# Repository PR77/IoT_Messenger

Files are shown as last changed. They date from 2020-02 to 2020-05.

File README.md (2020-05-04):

# IoT_Messenger
IoT Messenger (Pager) For Simple 1 Way Communication

# Warning
This design has not been compliance tested and will not be. It is published purely for inspiration to others. I take no responsibility for damages caused directly or indirectly. I accept no responsibility for any damage to any equipment that results from the use of this design and its components. IT IS ENTIRELY AT YOUR OWN RISK!

# Overview
As a child growing up in the 80's I have fond memories of old skool pagers and analog mobile phones the size of bricks. I remember buying a bunch of old analog Motorola (R) Brick Phones just before the analog network was shut down and turning them into scanners. This project is in no way connected to that, but the fond memory of pagers is something I wanted to bing back with this project. In addition to this, my other motivation for the project was it's "semi" practical use as a real pager within a known WiFi network.

## Basic Concept
My IoT Messenger is essentially some common components connected to an ESP8266, ESP12-F to be specific. However, it is the form factor and user interface which draws parallels to a pager. It is my first revision of the project and has a lot fo fine tuning - should I or the community want to pursue it further. I would like to continue improving this as I see it would be fun for those who use it.

Interfacing with the device is via the Web using the simple HTTP Server class. The IoT Messenger sends out a webpage where the message and other functions can be accessed. As my HTML and JS skills are not up there, I have resorted to using CURL during development and debugging - HELP NEEDED! :)

Here is a nice 3d model of the PCB;

### Appearance
Nice 3D model:
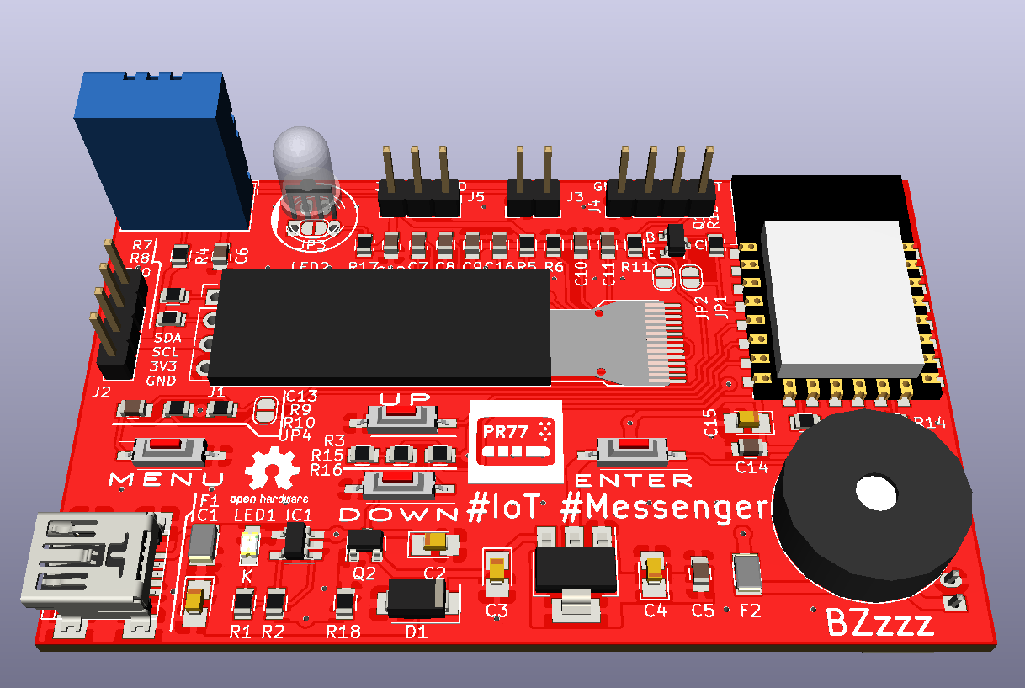
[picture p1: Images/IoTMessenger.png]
3DModel


### Basic Interfaces
My IoT Messenger needs to be portable therefore battery power and a basic set of controls are essential. I use a 600 mA LiPo cell which is charged via USB. USB provides power only. No intelligent power management has been implemented yet, so when running only via battery it last 4 - 5 hours.

There are 4 buttons for user input which can also be used for additional functions (see how Tetris and Dino game use them).

### Power Supply
I use the MCP73831 LiPo battery charger with a P-Channel load balancing FET. This is to ensure the LiPo charger only charges the battery when connected to a USB power source. The necessary 3.3 volts is obtained via a basic LM1117-3.3.

### Sensors And Indicators
I wanted to have the PCB somewhat universal - I guess like an evaluation or child friendly development board - so I added a nice RGB LED (PL9823) and an environmental sensor (DHT11). In addition to these, as the device is inspired by pagers, it has a OLED display (128x32) and Piezo Beeper.

As mentioned, flexibility was important so with the OLED, it is essentially dual-footprinted where a module with necessary passives could just be solder on, or the raw OLED panel and necessary passives be soldered on the IoT Messenger board. For my prototype I used the latter so get some experience with this. Lastly, I added a SAO port, well for - Add Ons.

Nice fully soldered IoT Messenger:
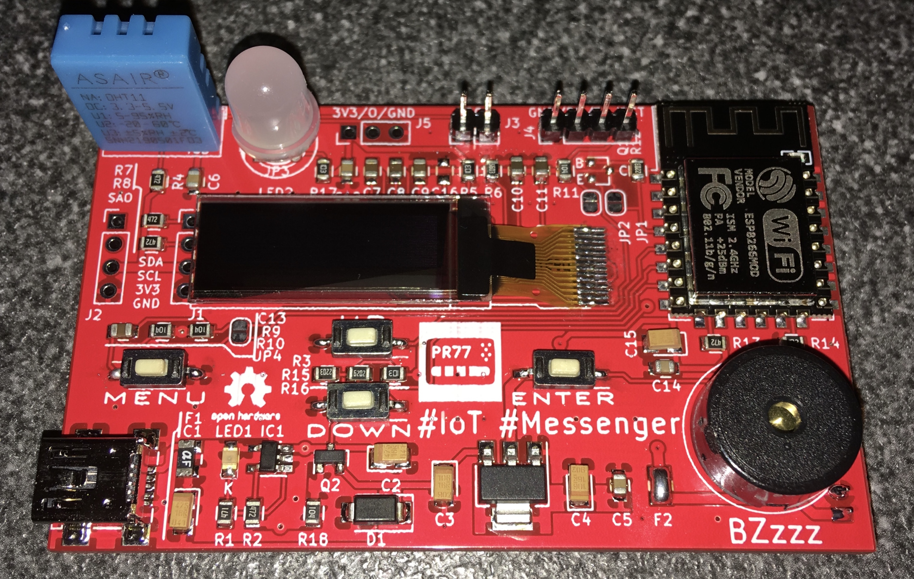
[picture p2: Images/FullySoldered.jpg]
FullySoldered


### Server
All of the interfacing with the hardware features is via HTTP Server GET and POST requests. The following services have been implemented currently;

|Request |Type|Parameters|Comments |
|---|----|---|---|
|/list |GET |none |Lists files currently saved to SPIFFS |
|/upload |POST|filename  |Uploads a file to SPIFFS |
|/format |POST|none |Formats SPIFFS |
|/info |GET |none |Get SPIFFS and CPU MHz info |
|/sensor |GET |none |Read environmental sensor data (DHT11)|
|/message|POST|text |Write a message to the buffer |
|/led |POST|colour |Set RGB LED colour |
|/beeper |POST|count |Beep piezo beeper |

### Fun Stuff
Of course. Check out my IoT Messenger playing the Tetris game theme music or Dino Jump. Videos are in the Images folder.

## Open Sources Used
PlatformIO is the main development environment. In addition to the Arduino framework for ESP8266, I used the following (either important as libraries into PIO or seperate);

1. OLED library (https://github.com/ThingPulse/esp8266-oled-ssd1306)
2. ClickButton library (https://github.com/pkourany/clickButton)
3. RGB LED library (https://github.com/Makuna/NeoPixelBus)
4. Tetris theme song (https://dragaosemchama.com/en/2019/02/songs-for-arduino/)
5. Environmental sensor library (https://github.com/beegee-tokyo/DHTesp)

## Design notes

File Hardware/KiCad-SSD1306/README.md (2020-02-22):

# KiCad-SSD1306_OLED-0.91-128x32

These are the KiCad files I create for the I2C SSD1306 0.91" 128x32 OLED display i used in my [Electrocard](http://michaelteeuw.nl/tagged/electrocard). I included a step file which can be used in a 3D rendering.

The absolute cumbersome and awful way of KiCad to manage libraries probably results in a wrongly setup directory or file structure for this KiCad part. Feel free to send a PR if it turns out it needs a different structure.

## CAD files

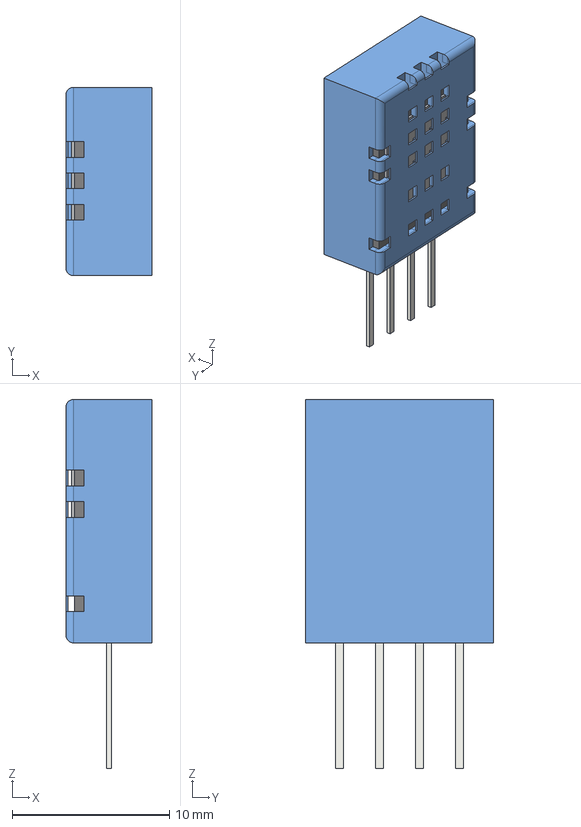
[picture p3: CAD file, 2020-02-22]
Hardware/KiCad-Sensors/Aosong_DHT11_5.5x12.0_P2.54mm.step
5.50 x 12.0 x 23.5 mm

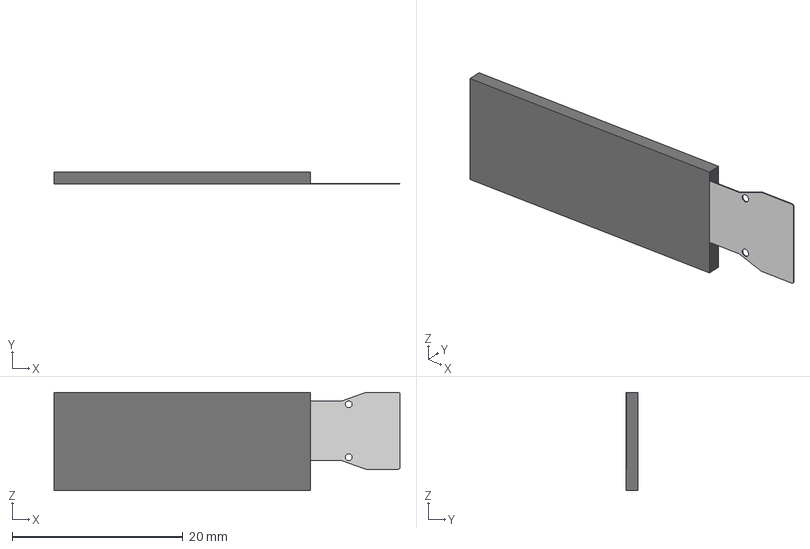
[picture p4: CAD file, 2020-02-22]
Hardware/KiCad-SSD1306/SSD1306_OLED-0.91-128x32.step
40.5 x 1.45 x 11.5 mm

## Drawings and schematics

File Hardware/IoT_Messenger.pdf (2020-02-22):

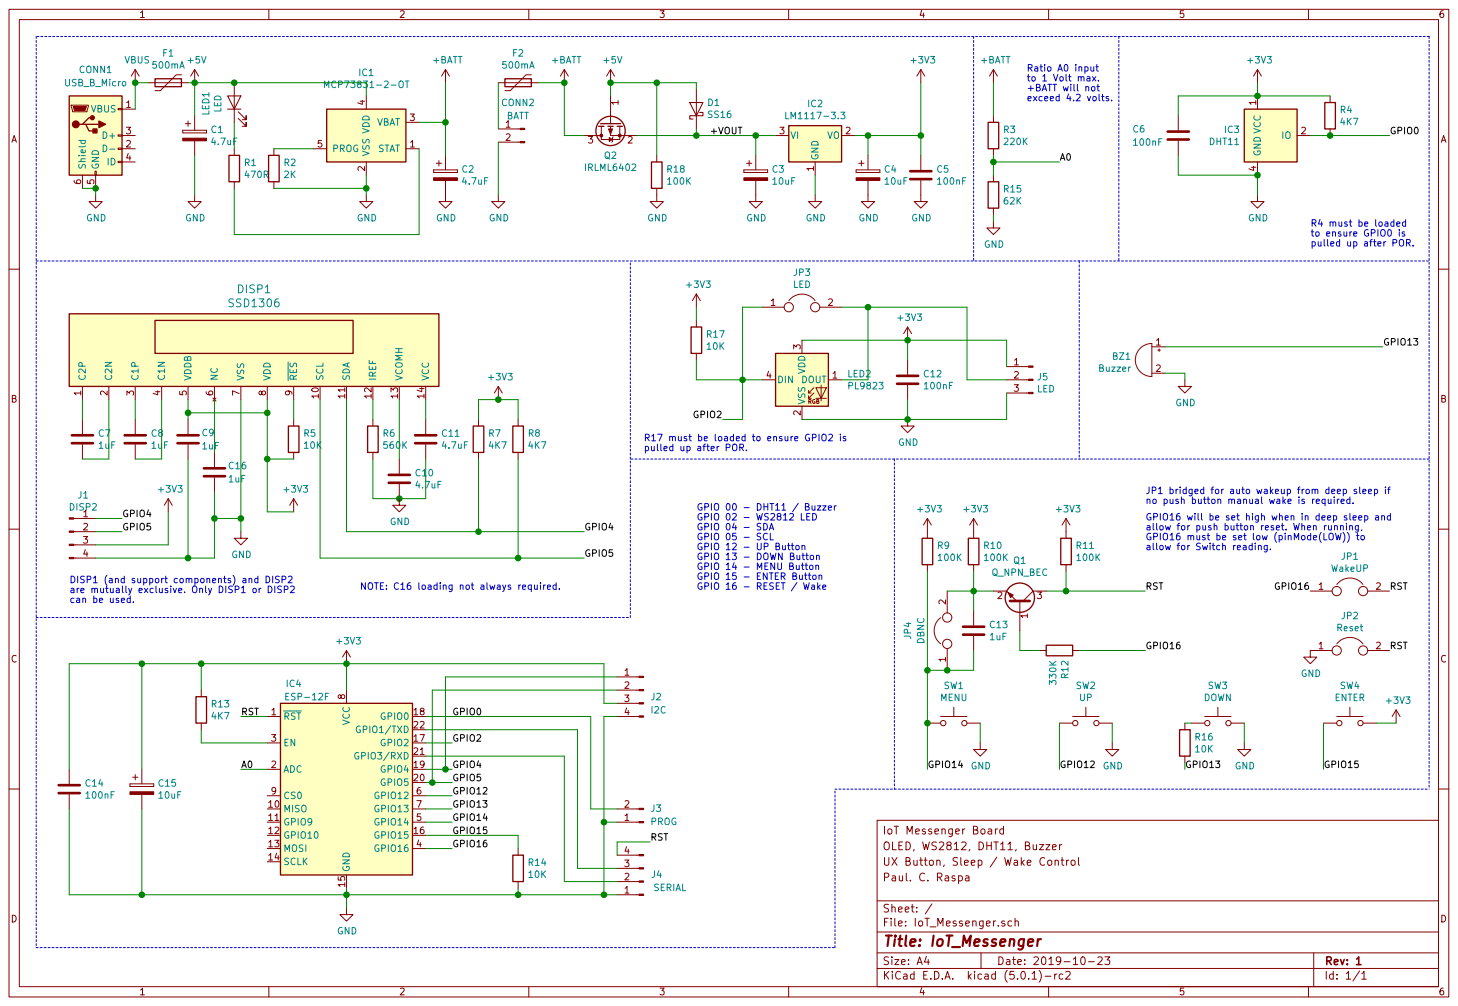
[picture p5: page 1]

Ratio A0 input
to 1 Volt max. +BATT will not exceed 4.2 volts.

4 PROG 5
+3V3 R17 must be loaded to ensure GPIO2 is pulled up after POR. RST

to ensure GPIO0 is pulled up after POR. R17

+3V3 GPIO4 GPIO5 +3V3 DISP1 (and support components) and DISP2

1 SCL 10 SDA 11 IREF 12 VCOMH 13 VCC 14 C2N

JP1 bridged for auto wakeup from deep sleep if

allow for push button reset. When running,
GPIO16 must be set low (pinMode(LOW)) to

allow for Switch reading. GPIO12 GPIO13 GPIO14 GPIO15 GPIO0

are mutually exclusive. Only DISP1 or DISP2

OLED, WS2812, DHT11, Buzzer
UX Button, Sleep / Wake Control
File: IoT_Messenger.sch Sheet: / Paul. C. Raspa

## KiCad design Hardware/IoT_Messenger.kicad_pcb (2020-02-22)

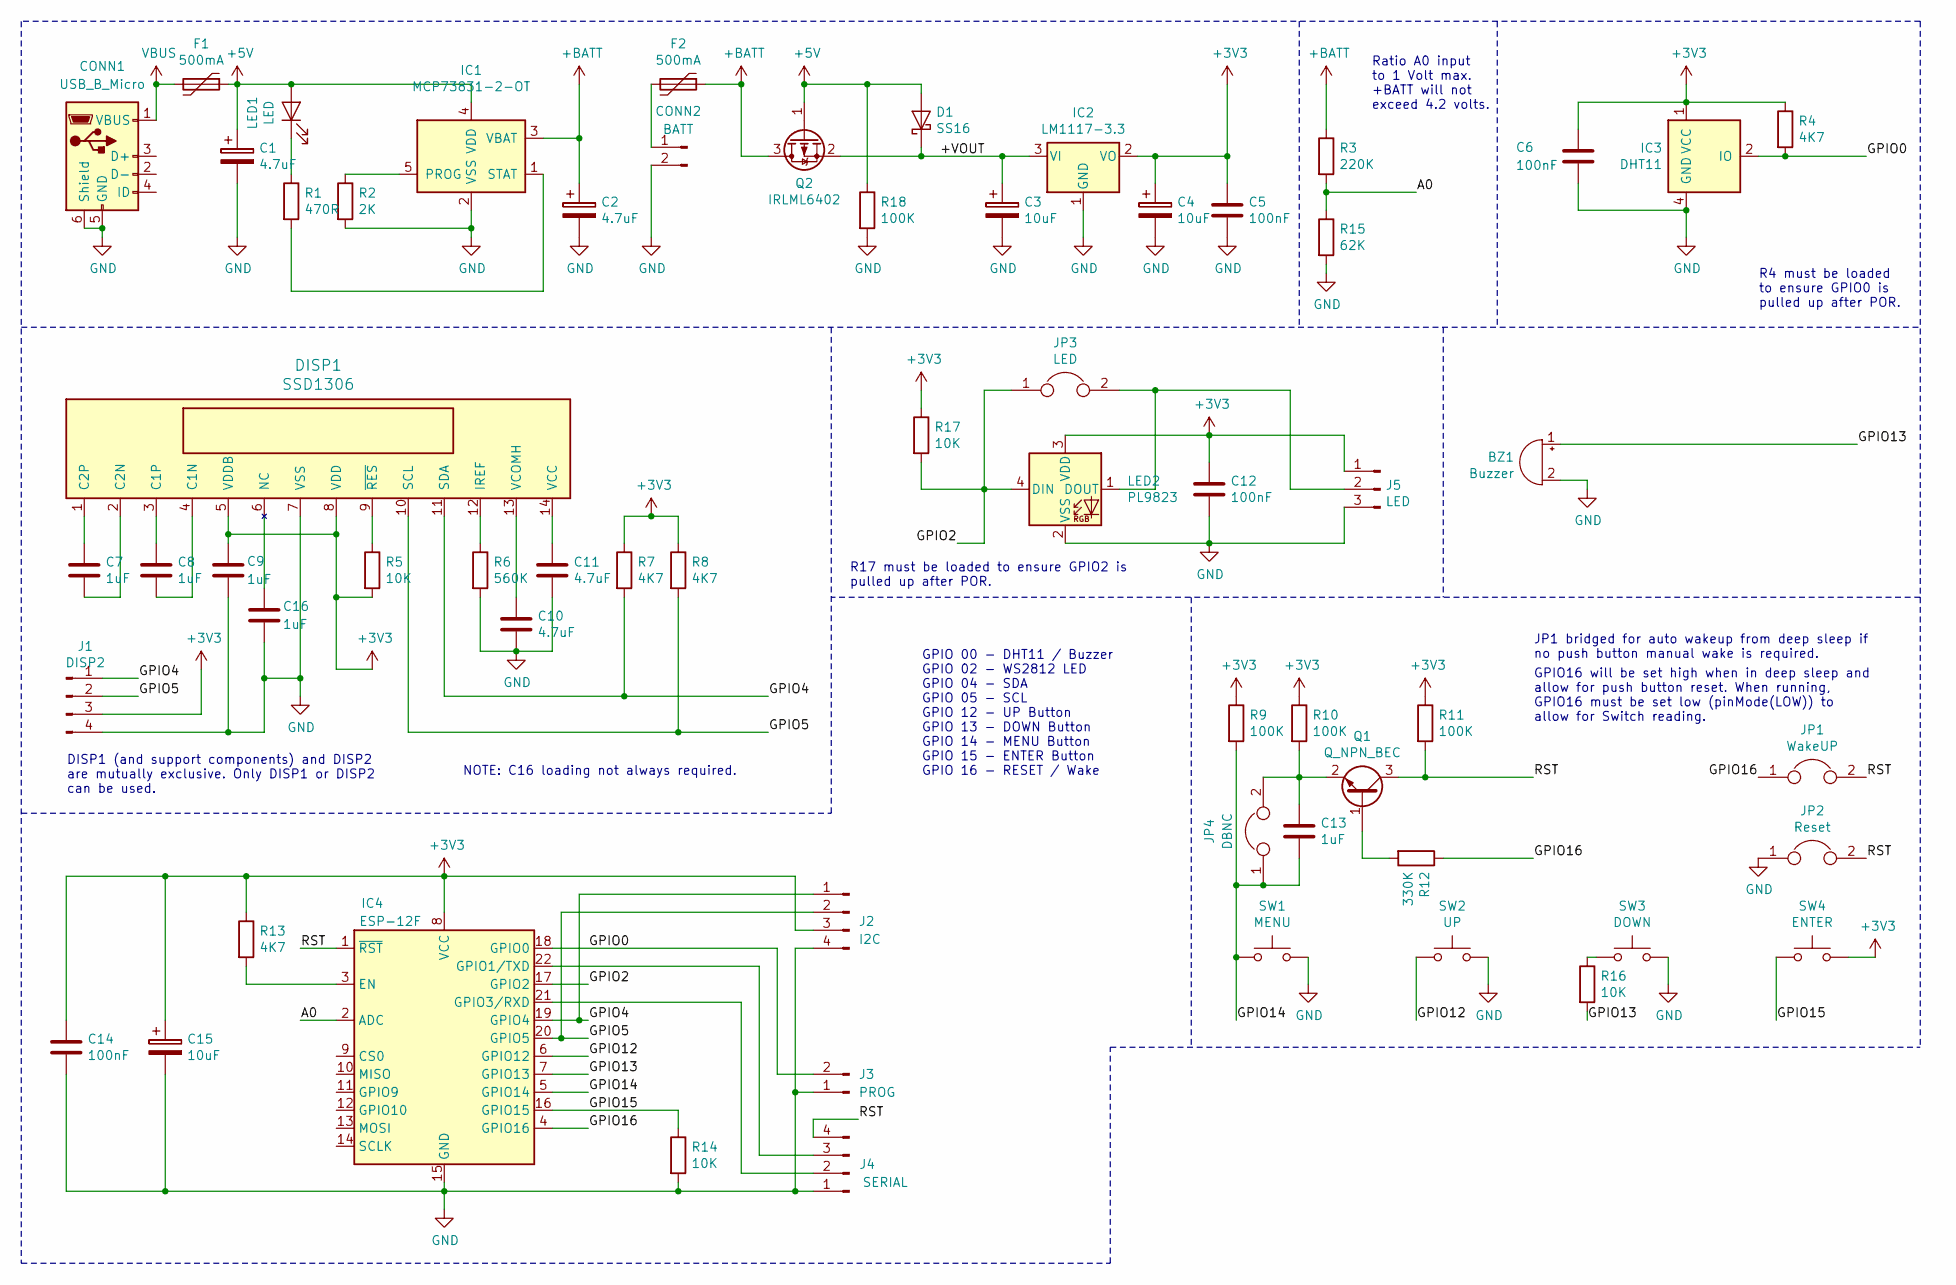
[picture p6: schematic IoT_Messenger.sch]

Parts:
BZ1: Buzzer; Buzzer_15x7.5RM7.6
C1, C2: 4.7uF; CP_Tantalum_Case-R_EIA-2012-12_Reflow
C3, C4, C15: 10uF; CP_Tantalum_Case-R_EIA-2012-12_Reflow
C5, C6, C12, C14: 100nF; C_0805
C7, C8, C9, C13, C16: 1uF; C_0805
C10, C11: 4.7uF; C_0805
CONN1: USB_B_Micro; USB_Mini-B
CONN2: BATT; JST_PH_S2B-PH-K_02x2.00mm_Angled
D1: SS16; D_SMA
DISP1: SSD1306; SSD1306_OLED-0.91-128x32
F1, F2: 500mA; Fuse_SMD1206_Reflow
IC1: MCP73831-2-OT; SOT-23-5_HandSoldering
IC2: LM1117-3.3; SOT-223-3_TabPin2
IC3: DHT11; Aosong_DHT11_5.5x12.0_P2.54mm
IC4: ESP-12F; ESP-12E
J1: DISP2; Pin_Header_Straight_1x04_Pitch2.54mm
J2: I2C; Pin_Header_Straight_1x04_Pitch2.54mm
J3: PROG; Pin_Header_Straight_1x02_Pitch2.54mm
J4: SERIAL; Pin_Header_Straight_1x04_Pitch2.54mm
J5: LED; Pin_Header_Straight_1x03_Pitch2.54mm
JP1: WakeUP; SolderJumper-2_P1.3mm_Open_RoundedPad1.0x1.5mm
JP2: Reset; SolderJumper-2_P1.3mm_Open_RoundedPad1.0x1.5mm
JP3: LED; SolderJumper-2_P1.3mm_Open_RoundedPad1.0x1.5mm
JP4: DBNC; SolderJumper-2_P1.3mm_Open_RoundedPad1.0x1.5mm
LED1: LED; LED_0805
LED2: PL9823; LED_D5.0mm-4
Q1: Q_NPN_BEC; SOT-23
Q2: IRLML6402; SOT-23
R1: 470R; R_0805
R2: 2K; R_0805
R3: 220K; R_0805
R4, R7, R8, R13: 4K7; R_0805
R5, R14, R16, R17: 10K; R_0805
R6: 560K; R_0805
R9, R10, R11, R18: 100K; R_0805
R12: 330K; R_0805
R15: 62K; R_0805
SW1: MENU; SW_DIP_x1_W7.62mm_Slide_Copal_CHS-B
SW2: UP; SW_DIP_x1_W7.62mm_Slide_Copal_CHS-B
SW3: DOWN; SW_DIP_x1_W7.62mm_Slide_Copal_CHS-B
SW4: ENTER; SW_DIP_x1_W7.62mm_Slide_Copal_CHS-B

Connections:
+3V3: C4.1, C5.1, C6.1, C9.1, C12.1, C14.1, C15.1, DISP1.5 (VDDB), DISP1.8 (VDD), IC2.2 (VO), IC3.1 (VCC), IC4.8 (VCC), J1.3, J2.3, J5.1, LED2.3 (VDD), R4.1, R5.2, R7.1, R8.1, R9.1, R10.1, R11.1, R13.1, R17.1, SW4.2
+5V: C1.1, D1.2 (A), F1.1, IC1.4 (VDD), LED1.2 (A), Q2.1 (G), R18.1
+BATT: C2.1, F2.1, IC1.3 (VBAT), Q2.3 (D), R3.1
/+VOUT: C3.1, D1.1 (K), IC2.3 (VI), Q2.2 (S)
/A0: IC4.2 (ADC), R3.2, R15.1
/GPIO0: IC3.2 (IO), IC4.18 (GPIO0), J3.2, R4.2
/GPIO2: IC4.17 (GPIO2), JP3.1, LED2.4 (DIN), R17.2
/GPIO4: DISP1.11 (SDA), IC4.19 (GPIO4), J1.1, J2.1, R7.2
/GPIO5: DISP1.10 (SCL), IC4.20 (GPIO5), J1.2, J2.2, R8.2
/GPIO12: IC4.6 (GPIO12), SW2.1
/GPIO13: BZ1.1 (-), IC4.7 (GPIO13), R16.2
/GPIO14: C13.2, IC4.5 (GPIO14), JP4.1, R9.2, SW1.1
/GPIO15: IC4.16 (GPIO15), R14.1, SW4.1
/GPIO16: IC4.4 (GPIO16), JP1.1, R12.1
/RST: IC4.1 (~RST), J4.4, JP1.2, JP2.2, Q1.3 (C), R11.2
GND: BZ1.2 (+), C1.2, C2.2, C3.2, C4.2, C5.2, C6.2, C9.2, C10.2, C11.2, C12.2, C14.2, C15.2, C16.2, CONN1.5 (GND), CONN1.6 (Shield), CONN2.2, DISP1.7 (VSS), IC1.2 (VSS), IC2.1 (GND), IC3.4 (GND), IC4.15 (GND), J1.4, J2.4, J3.1, J4.1, J5.3, JP2.1, LED2.2 (VSS), R2.2, R6.2, R14.2, R15.2, R18.2, SW1.2, SW2.2, SW3.2
unnamed: C7.1, DISP1.1 (C2P)
unnamed: C7.2, DISP1.2 (C2N)
unnamed: C8.1, DISP1.3 (C1P)
unnamed: C8.2, DISP1.4 (C1N)
unnamed: C10.1, DISP1.13 (VCOMH)
unnamed: C11.1, DISP1.14 (VCC)
unnamed: C13.1, JP4.2, Q1.2 (E), R10.2
unnamed: C16.1, DISP1.6 (NC)
unnamed: CONN2.1, F2.2
unnamed: DISP1.9 (~RES), R5.1
unnamed: DISP1.12 (IREF), R6.1
unnamed: IC1.1 (STAT), R1.2
unnamed: IC1.5 (PROG), R2.1
unnamed: IC4.3 (EN), R13.2
unnamed: IC4.21 (GPIO3/RXD), J4.2
unnamed: IC4.22 (GPIO1/TXD), J4.3
unnamed: J5.2, JP3.2, LED2.1 (DOUT)
unnamed: LED1.1 (K), R1.1
unnamed: Q1.1 (B), R12.2
unnamed: R16.1, SW3.1
VBUS: CONN1.1 (VBUS), F1.2

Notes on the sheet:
JP1 bridged for auto wakeup from deep sleep if no push button manual wake is required.
GPIO16 will be set high when in deep sleep and allow for push button reset. When running, GPIO16 must be set low (pinMode(LOW)) to allow for Switch reading.
DISP1 (and support components) and DISP2 are mutually exclusive. Only DISP1 or DISP2 can be used.
GPIO 00 - DHT11 / Buzzer GPIO 02 - WS2812 LED GPIO 04 - SDA GPIO 05 - SCL GPIO 12 - UP Button GPIO 13 - DOWN Button GPIO 14 - MENU Button GPIO 15 - ENTER Button GPIO 16 - RESET / Wake
Ratio A0 input to 1 Volt max. +BATT will not exceed 4.2 volts.
NOTE: C16 loading not always required.
R4 must be loaded to ensure GPIO0 is pulled up after POR.
R17 must be loaded to ensure GPIO2 is pulled up after POR.

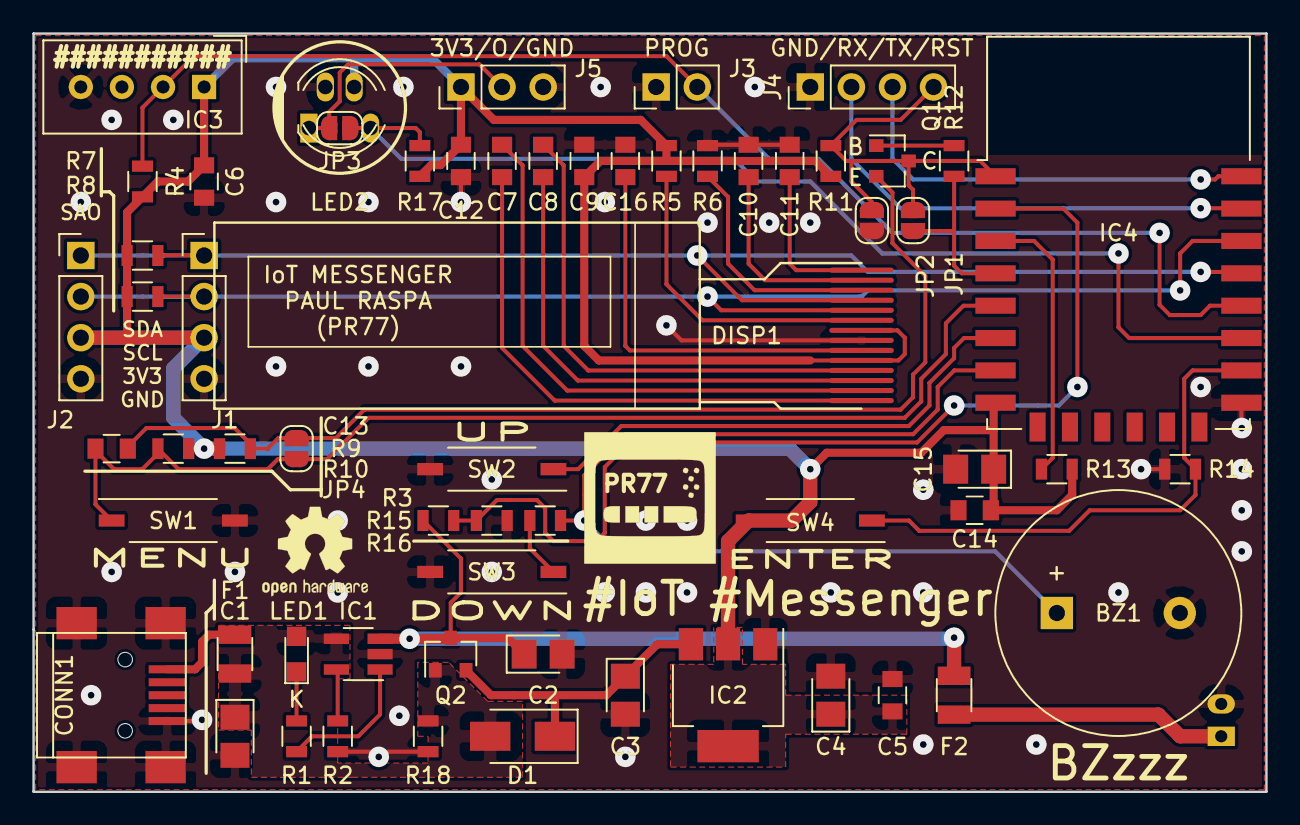
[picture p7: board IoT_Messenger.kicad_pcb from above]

Board: 2 copper layers, 76.2 x 46.9 mm, 62 parts (1 on the bottom side), 37 nets.

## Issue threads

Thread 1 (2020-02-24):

HW: OLED RST Circuit

PR77, 2020-02-24:
Add 100nF CAP between OLED RST Input and GND. OLED requires HW RST and SW (I2C) RST is not sufficient.

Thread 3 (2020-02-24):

HW: Input Poly Fuse Footprint

PR77, 2020-02-24:
Increase USB Input Poly Fuse footprint. Current is slightly too small for a 0805 device. Noticed that the Poly Fuses need a larger footprint for the solder to wick properly.

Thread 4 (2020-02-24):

HW: Button Foorprints

PR77, 2020-02-24:
Increase the solder pad landing side for the Buttons. Consider dual footprints to allow for other Buttons to be used.

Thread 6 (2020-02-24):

HW: RGB LED Footprint

PR77, 2020-02-24:
Currently using a PL9823 addressable RGB LED. Due to LED leg spacing, the leg holes needed to be offset to allow drilling. This make the component difficult to insert. Change to a PLCC-6 and use a WS2812b. Consider dual package.

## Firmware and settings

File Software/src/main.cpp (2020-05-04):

#include <Arduino.h>

#include <ESP8266WiFi.h>
#include <WiFiClient.h>
#include <ESP8266WebServer.h>
#include <ESP8266mDNS.h>
#include <ESP8266HTTPUpdateServer.h>
#include <FS.h>

#include <OLEDDisplay.h>
#include <OLEDDisplayFonts.h>
#include <OLEDDisplayUi.h>
#include <Wire.h>
#include <SSD1306.h>
#include <SSD1306Wire.h>
#include <NeoPixelBus.h>
#include <NTPClient.h>
#include <DHTesp.h>

#include <clickButton.h>
#include <beeperControl.h>
#include <batteryHistogram.h>

#include "uiGlobal.h"
#include "uiOverlay.h"
#include "uiFrameStatus.h"
#include "uiFrameMessage.h"
#include "uiFrameTime.h"
#include "uiFrameSensor.h"
#include "uiFrameTetris.h"
#include "uiFrameDino.h"
#include "uiFrameTunnel.h"
#include "uiFrameStars.h"
#include "uiFrameBattery.h"
#include "gameDino.h"
#include "gameTetris.h"
#include "gameTunnel.h"
#include "gameStars.h"

//=============================================================================
// Types
//=============================================================================

//=============================================================================
// Hostname, SSID and Password for Wifi router
//=============================================================================
#define HOSTNAME "IoTMessenger"

String staSSID(32);
String staPassword(32);

IPAddress apIPAddress(192,168,1,2);
IPAddress apGatwayAddress(192,168,1,1);
IPAddress apNetmask(255,255,255,0);

//=============================================================================
// Application specific defines and globals
//=============================================================================
const uint32_t blankUXAfterBootUp = 10L * (1000L);  // 10 seconds
const uint32_t blankUXAfterMessage = 10L;           // 10 seconds

static uint32_t lastDhtUpdateTime = 0;
static uint32_t lastLedUpdateTime = 0;

static uiGlobalState_e uiGlobalState = uiGlobalUXActive;
static bool ledNowOff = false;

//=============================================================================
// Global constants for NTP Client
//=============================================================================
const uint32_t utcOffsetInSeconds = 3600;

//=============================================================================
// Global constants for WS2182 interface, buttons, beeper interface, DHT11
//=============================================================================
const uint16_t PixelCount = 1;
const uint8_t PixelPin = 2;

const uint8_t EnterPin = 15;
const uint8_t MenuPin = 14;
const uint8_t UpPin = 12;
const uint8_t DownPin = 13;

const uint8_t BeeperPin = 13;

const uint8_t dhtSensorPin = 0;

const uint8_t DeepSleepPin = 16;

//=============================================================================
// Global objects for Wifi and ESP specifics
//=============================================================================
ESP8266WebServer httpServer(80);
ESP8266HTTPUpdateServer httpUpdater;
File fsUploadFile;

//=============================================================================
// OLED global object (https://github.com/ThingPulse/esp8266-oled-ssd1306)
//=============================================================================
SSD1306 display(0x3C, 4, 5, GEOMETRY_128_32);
OLEDDisplayUi ui(&display);

OverlayCallback overlays[] = { uiOverlay };
FrameCallback frames[] = { uiFrameStatus, uiFrameBattery, uiFrameMessage, uiFrameTime, uiFrameSensor, uiFrameTetris, uiFrameDino, uiFrameTunnel, uiFrameStars };
int overlaysCount = 1;
int frameCount = 9;

messageObject_s uiMessageObject = {"#IoT ... IoT ... IoT", false, false};

//=============================================================================
// Declare DHTxx object (DHT sensor library for ESPx by Bernd Giesecke)
//=============================================================================
DHTesp dht;
TempAndHumidity dhtTempAndHumidity;

//=============================================================================
// Global objects for NTP Client
//=============================================================================
WiFiUDP ntpUDP;
NTPClient timeClient(ntpUDP, "pool.ntp.org", utcOffsetInSeconds);

//=============================================================================
// Global objects for WS2812 NeoPixelBus object
//=============================================================================
NeoPixelBus<NeoRgbFeature, NeoEsp8266Uart1800KbpsMethod> rgbLed(PixelCount, PixelPin);

RgbColor red(255, 0, 0);
RgbColor green(0, 255, 0);
RgbColor blue(0, 0, 255);
RgbColor black(0, 0, 0);

//=============================================================================
// Global objects for ClickButton object
//=============================================================================
ClickButton enterButton(EnterPin, HIGH);
ClickButton menuButton(MenuPin, LOW, CLICKBTN_PULLUP);
ClickButton upButton(UpPin, LOW, CLICKBTN_PULLUP);
ClickButton downButton(DownPin, LOW, CLICKBTN_PULLUP);

//=============================================================================
// Global objects for beeper object
//=============================================================================
BeeperControl beeper(BeeperPin);

//=============================================================================
// Global objects for battery object
//=============================================================================
BatteryHistogram battery(true);

//=============================================================================
// Global objects for UX
//=============================================================================
uiGlobalObject_s uiGlobalObject = {&uiMessageObject, &dhtTempAndHumidity, &timeClient, &battery};

//=============================================================================
// Function prototypes
//=============================================================================
bool loadFromSpiffs(String path);
void handleRoot(void);
void handleFileList(void);
void handleFileUpload(void);
void handleWebRequests(void);
void handleSensor(void);
void handleMessage(void);
void handleLED(void);
void handleBeeper(void);

//=============================================================================
// Helper function
//=============================================================================

bool loadFromSpiffs(String path) {
    String dataType = "text/plain";
    bool fileTransferStatus = false;

    // If a folder is requested, send the default index.html
    if (path.endsWith("/")) {
        path += "index.htm";
    } else if (path.endsWith(".html")) dataType = "text/html";
    else if (path.endsWith(".htm")) dataType = "text/html";
    else if (path.endsWith(".css")) dataType = "text/css";
    else if (path.endsWith(".js")) dataType = "application/javascript";
    else if (path.endsWith(".png")) dataType = "image/png";
    else if (path.endsWith(".gif")) dataType = "image/gif";
    else if (path.endsWith(".jpg")) dataType = "image/jpeg";
    else if (path.endsWith(".ico")) dataType = "image/x-icon";
    else if (path.endsWith(".xml")) dataType = "text/xml";
    else if (path.endsWith(".pdf")) dataType = "application/pdf";
    else if (path.endsWith(".zip")) dataType = "application/zip";

    File dataFile = SPIFFS.open(path.c_str(), "r");

    if (!dataFile) {
        return fileTransferStatus;
    }
    else {
        if (httpServer.streamFile(dataFile, dataType) == dataFile.size()) {
            fileTransferStatus = true;
        }
    }

    dataFile.close();
    return fileTransferStatus;
}

//=============================================================================
// Webserver event handlers
//=============================================================================
void handleRoot(void) {
    httpServer.sendHeader("Location", "/index.html", true);

    // Redirect to our index.html web page
    httpServer.send(302, "text/plain", "");
}

void handleFileList(void) {
    // curl -X GET IoTMessenger.local/list

    String path = "/";
    String directoryList = "[";
    Dir directoryEntry = SPIFFS.openDir(path);

    while (directoryEntry.next()) {
        File fileElement = directoryEntry.openFile("r");

        if (directoryList != "[") {
            directoryList += ", ";
        }

        directoryList += String(fileElement.name()).substring(1);
        fileElement.close();
    }

    directoryList += "]";
    httpServer.send(200, "text/plain", directoryList);
}

void handleFileUpload(void) {
    // curl -X POST -F "file=@SomeFile.EXT" IoTMessenger.local/upload

    HTTPUpload& upload = httpServer.upload();

    if (upload.status == UPLOAD_FILE_START) {
        String filename = upload.filename;

        if (!filename.startsWith("/")) {
            filename = "/" + filename;
        }

        fsUploadFile = SPIFFS.open(filename, "w");

    } else if (upload.status == UPLOAD_FILE_WRITE) {

        if(fsUploadFile)
            fsUploadFile.write(upload.buf, upload.currentSize);

    } else if (upload.status == UPLOAD_FILE_END) {

        if(fsUploadFile) {
            fsUploadFile.close();
        }
    }
}

void handleWebRequests(void) {
    String message = "File Not Detected\n\n";

    if (loadFromSpiffs(httpServer.uri()))
        return;

    message += "URI: ";
    message += httpServer.uri();
    message += "\nMethod: ";
    message += (httpServer.method() == HTTP_GET) ? "GET" : "POST";
    message += "\nArguments: ";
    message += httpServer.args();
    message += "\n";

    for (uint8_t i = 0; i < httpServer.args(); i++) {
        message += " NAME:" + httpServer.argName(i);
        message += "\n VALUE:" + httpServer.arg(i) + "\n";
    }

    httpServer.send(404, "text/plain", message);
}

void handleSensor() {
    // curl -X POST IoTMessenger.local/sensor"

    String dht11Data = String();

    dht11Data = "{\"temperature\":" + String(dhtTempAndHumidity.temperature) + "}";
    dht11Data += "{\"humidity\":" + String(dhtTempAndHumidity.humidity) + "}";

    httpServer.send(200, "text/plain", dht11Data);
}

void handleMessage() {
    // curl -X POST IoTMessenger.local/message?text={TEXT MSG}"

    String messageRequestResponse = String();

    if (httpServer.hasArg("text")) {

        uiMessageObject.receivedMessage = httpServer.arg("text");
        uiMessageObject.newMessageReceived = true;
        uiMessageObject.messageRead = false;

        messageRequestResponse = "{\"success\":1}";

    } else {
        messageRequestResponse = "{\"no message specified\":2}";
    }

    httpServer.send(200, "text/plain", messageRequestResponse);
}

void handleLED() {
    // curl -X POST IoTMessenger.local/led?colour=%23{RRGGBB}"

    String ledRequestResponse = String();

    if (httpServer.hasArg("colour")) {
        HtmlColor pixelColour = HtmlColor();
        pixelColour.Parse<HtmlColorNames>(httpServer.arg("colour"));

        rgbLed.SetPixelColor(0, pixelColour);
        rgbLed.Show();

        ledRequestResponse = "{\"success\":1}";
    } else {
        ledRequestResponse = "{\"no colour specified\":3}";
    }

    httpServer.send(200, "text/plain", ledRequestResponse);
}

void handleBeeper() {
    // curl -X POST IoTMessenger.local/beeper?count={BEEPS}"

    String beeperRequestResponse = String();

    if (beeper.GetBeeperState() == beepHandlerIdle) {
        if (httpServer.hasArg("count")) {
            beeper.RequestBeeper(httpServer.arg("count").toInt());

            beeperRequestResponse = "{\"success\":1}";
        } else {
            beeperRequestResponse = "{\"no count specified\":4}";
        }
    }
    else {
        beeperRequestResponse = "{\"busy\":5}";
    }

    httpServer.send(200, "text/plain", beeperRequestResponse);
}

//=============================================================================
// Setup function
//=============================================================================
void setup() {
    File fsWifiConfig;
    uint32_t apModeStartTime = 0;
    uint8_t connectionProgress = 0;
    bool apMode = false;

    // Initialise serial object
    Serial.begin(115200);

    // Initialize deep sleep pin to allow for wakeup
    pinMode(DeepSleepPin, OUTPUT);
    digitalWrite(DeepSleepPin, LOW);

    // Initialise battery charge state GetBatteryHistogram
    battery.Init();

    // Initialize File System
    SPIFFS.begin();

    // This resets all the neopixels to an off state
    rgbLed.Begin();
    rgbLed.SetPixelColor(0, black);
    rgbLed.Show();

    // Initialise OLED display driver
    display.init();
    display.resetDisplay();
    display.flipScreenVertically();

    // AP if no wifi.config file exists or if UP Button pressed for 1 second.
    if (!SPIFFS.exists("/wifi.conf")) {
        apMode = true;
    } else {
        apModeStartTime = millis();

        while (digitalRead(UpPin) == LOW) {
            if ((millis() - apModeStartTime) >= 1000) {
                apMode = true;
                break;
            }
        }
    }

    if (apMode == true) {
        WiFi.mode(WIFI_AP);
        WiFi.softAPConfig(apIPAddress, apGatwayAddress, apNetmask);
        WiFi.softAP("IoTMsgSetup");

        rgbLed.SetPixelColor(0, blue);
        rgbLed.Show();
    } else {
        fsWifiConfig = SPIFFS.open("/wifi.conf", "r");

        if (!fsWifiConfig) {
            rgbLed.SetPixelColor(0, red);
            rgbLed.Show();
            delay(5000);
            ESP.reset();
        }

        staSSID = fsWifiConfig.readStringUntil(',');
        staPassword = fsWifiConfig.readStringUntil(',');
        fsWifiConfig.close();

        WiFi.setSleepMode(WIFI_NONE_SLEEP);
        WiFi.mode(WIFI_STA);
        WiFi.begin(staSSID, staPassword);

        // Wait for connection
        while (WiFi.status() != WL_CONNECTED) {
            display.drawProgressBar(0, 0, 127, 31, connectionProgress);
            display.display();

            connectionProgress += 10;

            if (connectionProgress > 100) {
                display.clear();
                connectionProgress = 0;
            }

            delay(100);
        }

        rgbLed.SetPixelColor(0, green);
        rgbLed.Show();
    }

    WiFi.hostname(HOSTNAME);

    if (MDNS.begin(HOSTNAME)) {
        MDNS.addService("http", "tcp", 80);
    }

    // Start servers
    httpServer.begin();
    httpUpdater.setup(&httpServer);

    // Attached to NTP Client
    timeClient.begin();

    // Setup UI
    ui.setTargetFPS(10);
    ui.disableAllIndicators();
    ui.disableAutoTransition();
    ui.setOverlays(overlays, overlaysCount);
    ui.setFrames(frames, frameCount);
    ui.getUiState()->userData = (void *)&uiGlobalObject;
    ui.init();
    display.flipScreenVertically();

    // Setup DHT11 interface
    dht.setup(dhtSensorPin, DHTesp::DHT11);

    // Assign server helper functions
    httpServer.on("/", handleRoot);
    httpServer.on("/list", HTTP_GET, handleFileList);
    httpServer.on("/sensor", HTTP_GET, handleSensor);
    httpServer.on("/info", HTTP_GET, []() {
        String spiffsInfo = String();
        FSInfo fsInfo;

        SPIFFS.info(fsInfo);
        spiffsInfo = "TotalByte: " + String(fsInfo.totalBytes);
        spiffsInfo += " UsedBytes: " + String(fsInfo.usedBytes);
        spiffsInfo += " Flash Chip: " + String(ESP.getFlashChipRealSize());
        spiffsInfo += " CPU Freq: " + String(ESP.getCpuFreqMHz());
        httpServer.send(200, "text/plain", spiffsInfo);
    });

    httpServer.on("/upload", HTTP_POST, []() {
        httpServer.send(200, "text/plain", "{\"success\":1}");
    }, handleFileUpload);

    httpServer.on("/format", HTTP_POST, []() {
        SPIFFS.format();
        httpServer.send(200, "text/plain", "{\"success\":1}");
    });

    httpServer.on("/message", HTTP_POST, handleMessage);
    httpServer.on("/led", HTTP_POST, handleLED);
    httpServer.on("/beeper", HTTP_POST, handleBeeper);

    httpServer.onNotFound(handleWebRequests);

    lastDhtUpdateTime = millis();
    lastLedUpdateTime = millis();
}

//=============================================================================
// Loop function
//=============================================================================
void loop() {

    static beepHandler_t previousBeeperState = beepHandlerIdle;
    uint32_t currentTime = millis();
    uint16_t uiRemainingBudget = 0;

    menuButton.Update();
    enterButton.Update();
    upButton.Update();

    // Only debounce downButton if beeper is idle (not blocked or not active)
    if (beeper.GetBeeperState() == beepHandlerIdle) {
        if (previousBeeperState != beepHandlerIdle) {
            previousBeeperState = beepHandlerIdle;

            // Once beeper is finished, set pin to input again
            pinMode(DownPin, INPUT_PULLUP);
        }

        downButton.Update();
    } else {
        // Beeper blocked or active so save previous state for edge detection
        previousBeeperState = beeper.GetBeeperState();
    }

    switch (uiGlobalState) {
        case uiGlobalUXActive:
        {
            if (ui.getUiState()->currentFrame == 5) {
                if (enterButton.clicks > 0) {

                    // Block beeper to prevent clickButton detecting button
                    // pressed when beeper is active
                    beeper.RequestBlock();
                    uiGlobalState = uiGlobalUXTetris;
                }
            }

            if (ui.getUiState()->currentFrame == 6) {
                if (enterButton.clicks > 0) {
                    uiGlobalState = uiGlobalUXDino;
                }
            }

            if (ui.getUiState()->currentFrame == 7) {
                if (enterButton.clicks > 0) {
                    uiGlobalState = uiGlobalUXTunnel;
                }
            }

            if (ui.getUiState()->currentFrame == 8) {
                if (enterButton.clicks > 0) {
                    uiGlobalState = uiGlobalUXStars;
                }
            }

            uiRemainingBudget = ui.update();

            if (menuButton.clicks > 0) {
                ui.nextFrame();
            } else if (menuButton.clicks < 0) {
                ui.previousFrame();
            }
        }
        break;

        case uiGlobalUXTetris:
        {
            if (gameTetrisCyclic((OLEDDisplay *)&display, &upButton, &downButton, &enterButton, &menuButton, &uiRemainingBudget) == gameTetrisStateExit) {

                // Unblocker beeper will cause pinMode to be set back to input
                beeper.RequestUnblock();

                // Update last UI upadate timer with current time to avoid frame skipping
                ui.getUiState()->lastUpdate = currentTime;
                uiGlobalState = uiGlobalUXActive;
            }
        }
        break;

        case uiGlobalUXDino:
        {
            if (gameDinoCyclic((OLEDDisplay *)&display, &upButton, &menuButton, &uiRemainingBudget) == gameDinoStateExit) {

                // Update last UI upadate timer with current time to avoid frame skipping
                ui.getUiState()->lastUpdate = currentTime;
                uiGlobalState = uiGlobalUXActive;
            }
        }
        break;

        case uiGlobalUXTunnel:
        {
            if (gameTunnelCyclic((OLEDDisplay *)&display, &menuButton, &uiRemainingBudget) == gameTunnelStateExit) {

                // Update last UI upadate timer with current time to avoid frame skipping
                ui.getUiState()->lastUpdate = currentTime;
                uiGlobalState = uiGlobalUXActive;
            }
        }
        break;

        case uiGlobalUXStars:
        {
            if (gameStarsCyclic((OLEDDisplay *)&display, &menuButton, &uiRemainingBudget) == gameStarsStateExit) {

                // Update last UI upadate timer with current time to avoid frame skipping
                ui.getUiState()->lastUpdate = currentTime;
                uiGlobalState = uiGlobalUXActive;
            }
        }
        break;

        default:
            uiGlobalState = uiGlobalUXActive;
            break;
    }

    if (uiRemainingBudget > 0) {
        httpServer.handleClient();
        beeper.Update();
        battery.Update();
        MDNS.update();

        if ((currentTime - lastDhtUpdateTime) >=  2000) {
            dhtTempAndHumidity = dht.getTempAndHumidity();

            lastDhtUpdateTime = currentTime;
        }

        if (((currentTime - lastLedUpdateTime) >=  2000) && (ledNowOff == false)) {
            rgbLed.SetPixelColor(0, black);
            rgbLed.Show();

            ledNowOff = true;
            lastLedUpdateTime = currentTime;
        }

        if (downButton.clicks < 0) {
            // If DOWN button held for longer than 1 second go to sleep
            display.displayOff();
            digitalWrite(DeepSleepPin, HIGH);
            ESP.deepSleep(ESP.deepSleepMax(), WAKE_RF_DEFAULT);
        }
    }
}

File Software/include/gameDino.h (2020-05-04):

#ifndef GAME_DINO
#define GAME_DINO

#include "Arduino.h"

#include <clickButton.h>

#include <OLEDDisplay.h>
#include <OLEDDisplayFonts.h>
#include <OLEDDisplayUi.h>

//=============================================================================
// Defines
//=============================================================================

#define DINO_GAME_REFRESH               33  // 30 FPS

#define DINO_SPRITE_WIDTH               16
#define DINO_SPRITE_HEIGHT              13

#define CLOUD_SPRITE_COUNT              4
#define CLOUD_SPRITE_COMPLETE_INDEX     (CLOUD_SPRITE_COUNT - 1)
#define CLOUD_SPRITE_WIDTH              16
#define CLOUD_SPRITE_HEIGHT             5
#define CLOUD_SCROLL_STEP               1
#define CLOUD_REFRESH_DELAY             3

#define MAX_DIRT_COUNT                  3
#define MAX_OBSTACLES                   1
#define OBSTACLE_SCROLL_STEP            1
#define OBSTACLE_REFRESH_DELAY          3

#define GAME_OVER_FLASH_COUNT           6
#define GAME_OVER_FLASH_STEP            1
#define GAME_OVER_REFRESH_DELAY         3

//=============================================================================
// Types
//=============================================================================

typedef enum {

    gameDinoStateIdle = 0,
    gameDinoStateRunning,
    gameDinoStateGameOver,
    gameDinoStateExit

} gameDinoState_e;

typedef enum {

    noCollision = 0,
    collisionWithObstacle

} gameDinoCollision_e;

typedef enum {

    displayFlashing = 0,
    displayScore

} gameDinoGameOver_e;

typedef enum {

    jumpingUp = 0,
    comingDown

} gameDinoJumpDirection_e;

typedef enum {

    cloudForming = 0,
    cloudScrolling

} gameDinoCloudState_e;

typedef struct {

    uint8_t width;
    uint8_t height;
    uint8_t speed;
    uint8_t xPosition;
    uint8_t yPosition;

} gameDinoObstacle_s;

typedef struct {

    gameDinoState_e gameDinoState;
    uint16_t dinoScore;
    gameDinoObstacle_s dinoObstacle[MAX_OBSTACLES];
    uint8_t obstacleRefreshDelay;
    uint8_t dirtPixels[MAX_DIRT_COUNT];
    uint8_t dinoGravity;
    uint32_t refreshTimer;
    uint8_t dinoYPosition;
    uint8_t cloudXPosition;
    gameDinoCloudState_e cloudState;
    uint8_t cloudSprintIndex;
    uint8_t cloudRefreshDelay;
    gameDinoJumpDirection_e dinoJumpDirection;
    bool jumpPressed;
    bool dinoJumping;
    gameDinoGameOver_e gameOverState;
    uint8_t gameOverRefreshDelay;
    uint8_t gameOverFlashCount;

} gameDinoObject_s;

//=============================================================================
// Prototypes
//=============================================================================

gameDinoState_e gameDinoCyclic(OLEDDisplay *display, ClickButton *jump, ClickButton *exit, uint16_t *gameRemainingBudget);

#endif // GAME_DINO

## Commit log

2020-02-24 Updates
    Fixed bug where UI would block during frame skipping recovery.
    [main.cpp]
2020-02-29 Updates
    Inproved Status Frame to show AP IP Address.
2020-04-15 Updates
    Added a Battery Voltage Histogram Frame.
2020-04-21 Updates
    Improved beeper support and better battery histogram
